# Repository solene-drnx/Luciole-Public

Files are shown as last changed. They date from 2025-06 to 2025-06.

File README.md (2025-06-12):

# 🛋️ Tuto faire une lampe connectée 
Petit dossier pour vous montrer comment faire une lampe connectée.
La lampe a les fonctionnalités suivantes : 
- **Réveil simulateur d'aube** : La lampe monte en luminosité progressive pour te réveiller en douceur en 30 min en fonction de l'heure de ton réveil
- **Radio intégrée** : La lampe intègre une radio pour te permettre d'écouter de la musique ou les informations
- **Contrôle via une application** : La lampe est connectée à une application mobile pour te permettre de contrôler à distance la couleur de cette dernière, la fréquence radio ou encore l'heure des réveils.

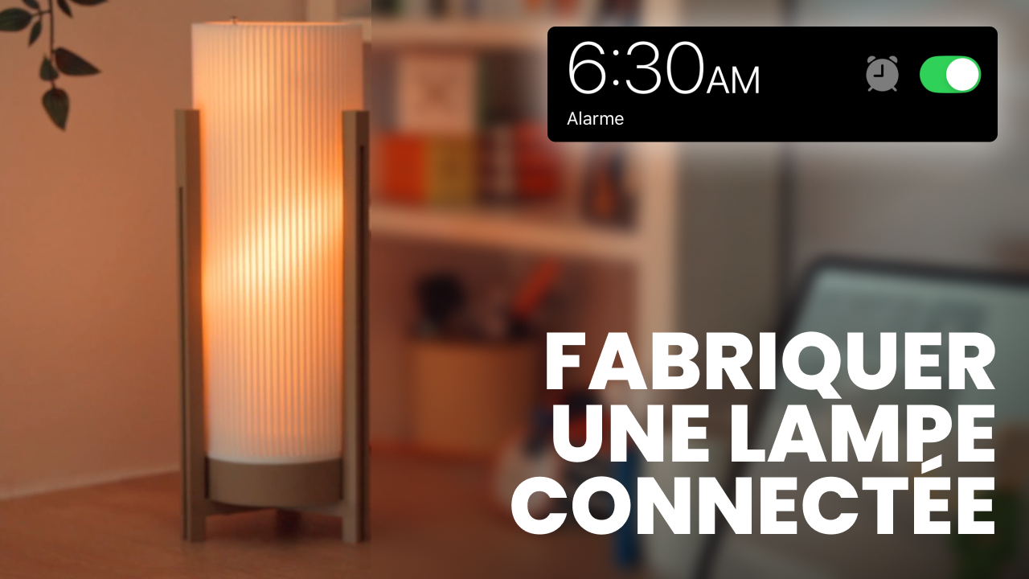
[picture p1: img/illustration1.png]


##  ⚙️ Matériel 
Pour le matériel, il te faudra les composants suivants. Si tu ne veux pas de module radio tu peux prendre uniquement l'ESP32 et le ruban de LED.
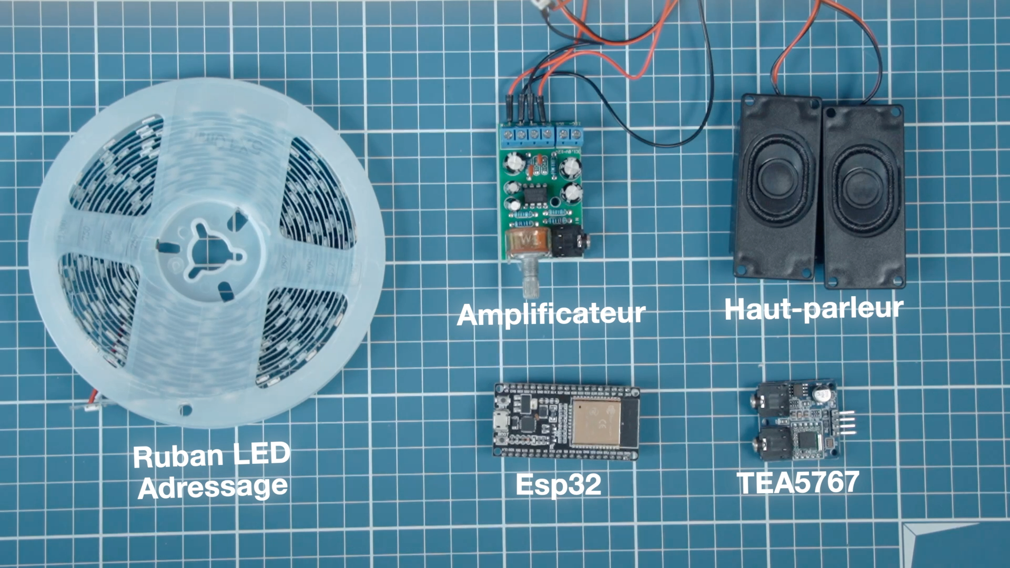
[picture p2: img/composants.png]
composants


| Composant | Prix |
|---|---|
| [ESP32](https://www.amazon.fr/AZDelivery-Development-successeur-Compatible-incluant/dp/B071P98VTG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,aps,90&sr=8-6&th=1) | 10.19 € |
| [Module radio TEA5767](https://www.amazon.fr/ICQUANZX-TEA5767-antenne-t%C3%A9lescopique-76-108MHZ/dp/B07VBVDNLL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) | 9,99 €  | |
| [Amplificateur Audio TDA2822M](https://www.amazon.fr/DC1-8-12V-dAmplificateur-Puissance-Ordinateur-Haut-parleur/dp/B07LG35G22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) | 5 € | |
| [Haut parleur](https://www.amazon.fr/CQRobot-Electronics-JST-PH2-0-Interface-Electronic/dp/B0738NLFTG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) | 7,99 €  | |
| [LED adressables](https://www.amazon.fr/Yeexppz-Dimmable-Individually-Addressable-Intelligent/dp/B0C5R5HMK6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) | 20.29 € | | | |
| [Câble jack jack](https://www.amazon.fr/dp/B07KTYS6FB?ref=ppx_yo2ov_dt_b_fed_asin_title) | 2,35 €  | |

## 🛒 Branchements
Branchements entre le module radio et L'ESP32

| ESP32 | Module Radio TEA5767 | 
| --- |---|
| 5V | 5V | 
| GPIO21 | SDA |
| GPIO22 | SCL | 
| GND | GND |

Ensuite brancher le module Radio TEA5767 avec l'amplificateur Audio TDA2822M grâce au cable jack-jack. Puis brancher l'amplificateur aux deux enceintes et l'alimenter en 5V.  

Branchement entre le ruban de LED et l'ESP32 : 

| ESP32 | Ruban de LED | 
| --- |---|
| 5V | 5V | 
| GPIO2 | DIN |
| GND | GND |

## 🚧 Code ESP32
### Récupérer l'adresse IP locale de l'ESP32
Dans un premier temps, on va récupérer l'adresse IP locale de l'ESP32. Pour cela lance le script [IP local](ESP32/IPlocal/IPlocal.ino) dans le dossier ESP32.  
Ouvrez le `Serial Monitor` pour récupérer l'adresse IP locale de l'ESP32.

### Code final de l'ESP32

Ensuite téléverser le [script final](ESP32/scriptESP32/scriptESP32.ino) dans l'ESP32 qui se situe dans le dossier `script ESP32`.

## 🔮 Application
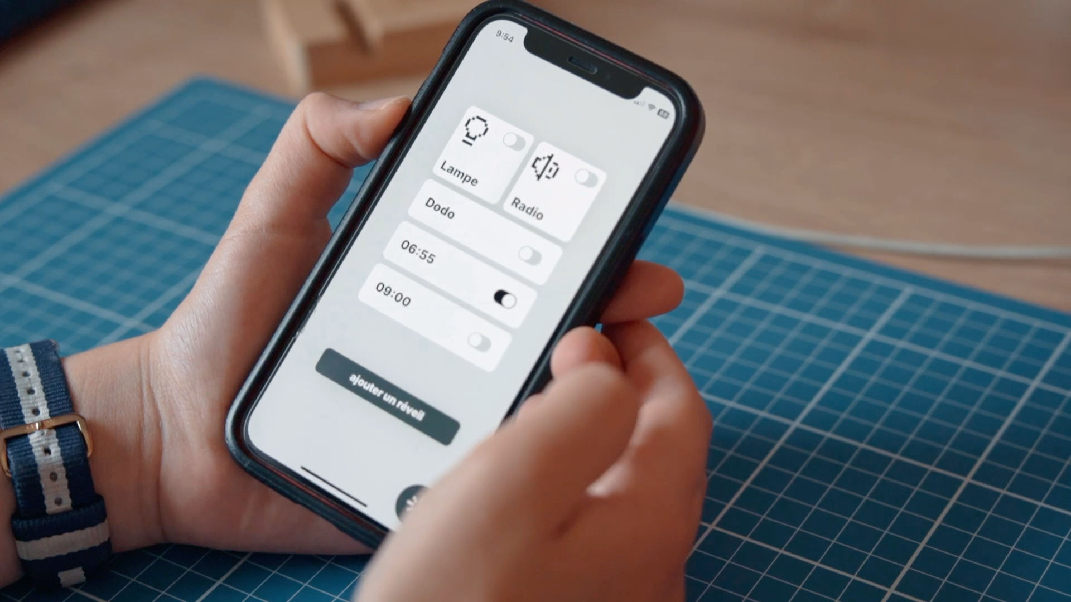
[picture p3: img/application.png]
image application


Il vous faudra les prérequis suivant pour installer l'application. 
- Node.js et npm/yarn.
- Expo CLI installé.

1. Va dans le [dossier ici](Application/):
2. Installe les dépendances : `npm install`
3. Lance l'application : `npx expo start`

Ensuite ajoute l'adresse IP local de l'ESP32 dans le fichier [config.js](Application/config/config.js) pour pouvoir faire en sorte que l'application communique avec l'ESP32.

## Assemblage

Ensuite il vous faudra imprimer les fichiers 3D suivant. Il est important d'imprimer le diffuseur en blanc afin qu'il diffuse la lumière, pour le reste c'est comme vous voulez ✌️

Pour assembler la lampe il faut que tu mette l'ESP32 et les branchement dans le [conteneur électronique](Fichiers%203D/conteneurElectronique.stl). Ensuite tu peux caler la [pièce qui fait le lien avec le cylindre](Fichiers%203D/lienConteneurCylindre.stl). Puis tu peux placer le [cylindre](Fichiers%203D/cylindreLED.stl) au dessus et coller le ruban de LED dessus.

L'assemblage de ces trois pièces devrait ressembler à cela : 
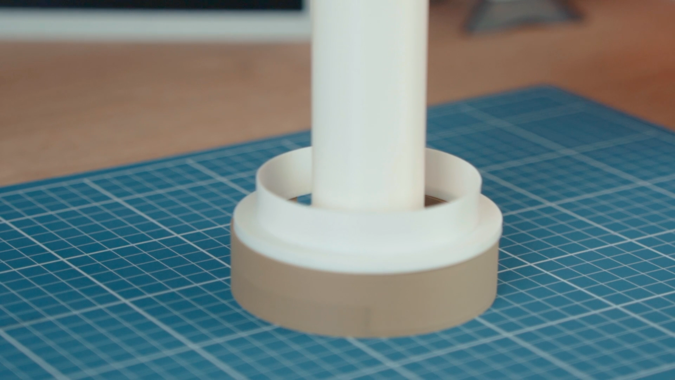
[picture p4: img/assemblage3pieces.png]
assemblage


Tu peux ensuite mettre les enceintes et l'amplificateur dans le cylindre. Tu peux ensuite mettre le [diffuseur](Fichiers%203D/diffuseur.stl) et le [cadre](Fichiers%203D/cadreEnBois.stl).

## Conclusion

Et voila y'a plus qu'à alimenter ta lampe et elle devrait ressembler à ca 🥳

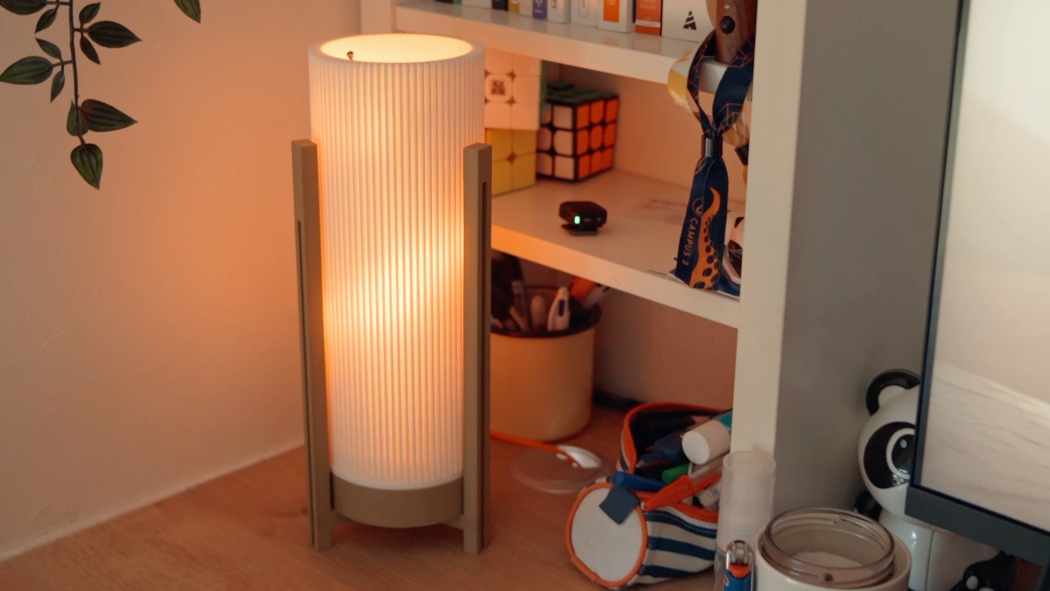
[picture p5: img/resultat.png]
resultat final


Voila voila 🤗  
Des bisous  
Solène

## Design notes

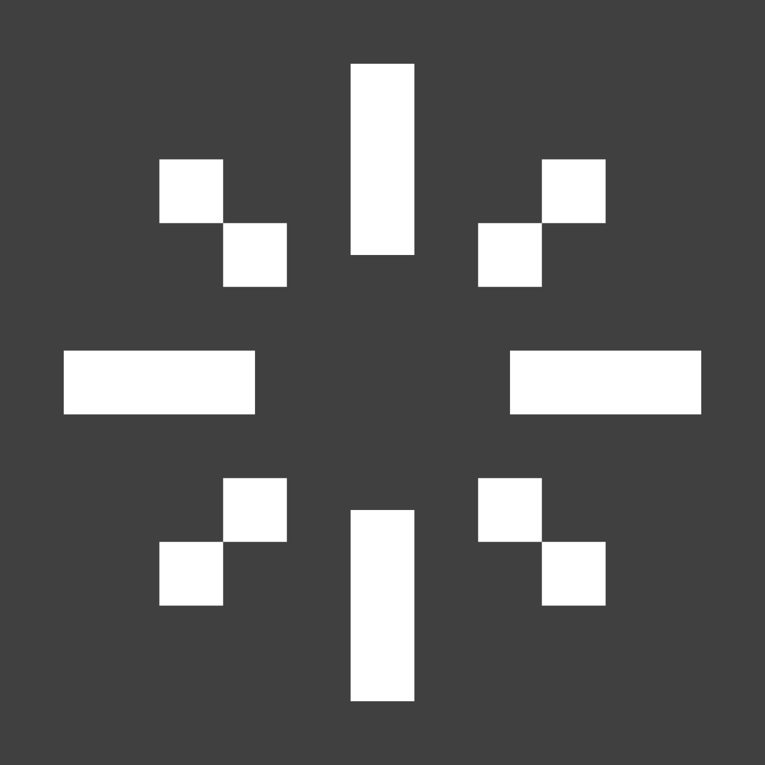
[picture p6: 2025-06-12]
Application/assets/loader.png

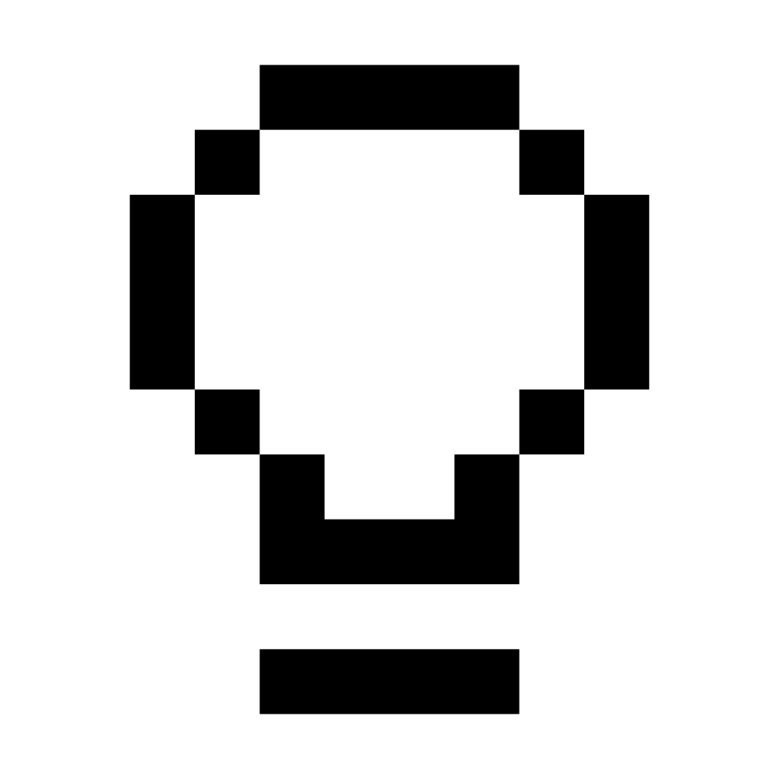
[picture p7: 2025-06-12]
Application/assets/lightbulb.png

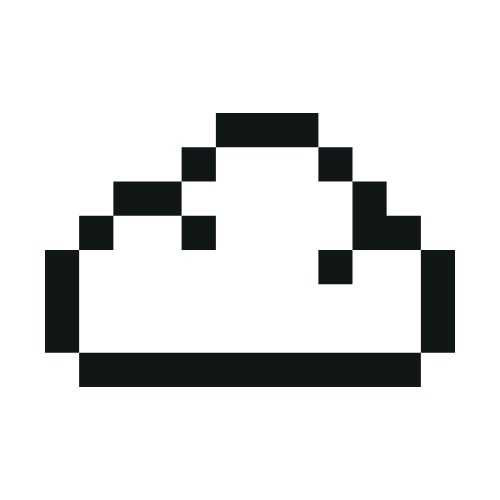
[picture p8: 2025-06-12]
Application/assets/cloud.png

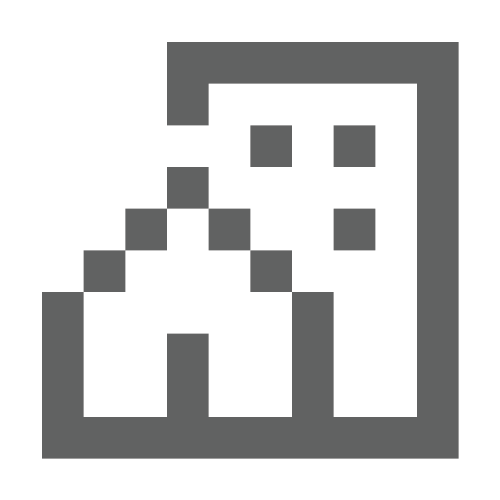
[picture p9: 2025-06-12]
Application/assets/greyBus.png

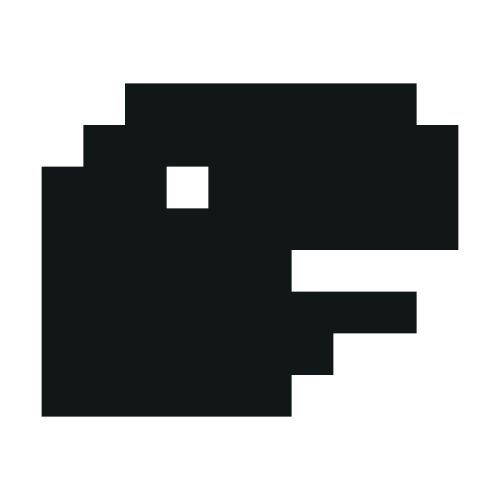
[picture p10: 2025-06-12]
Application/assets/dino.png

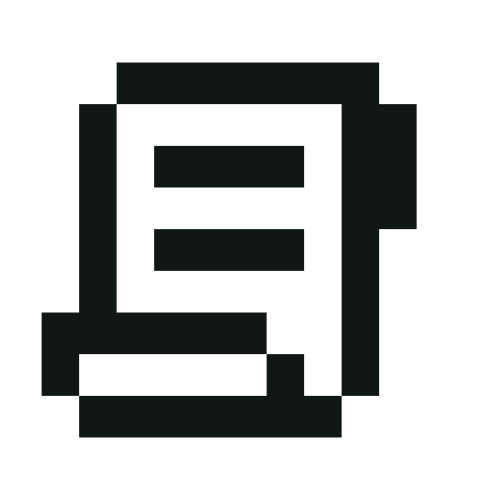
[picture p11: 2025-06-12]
Application/assets/script_text.png

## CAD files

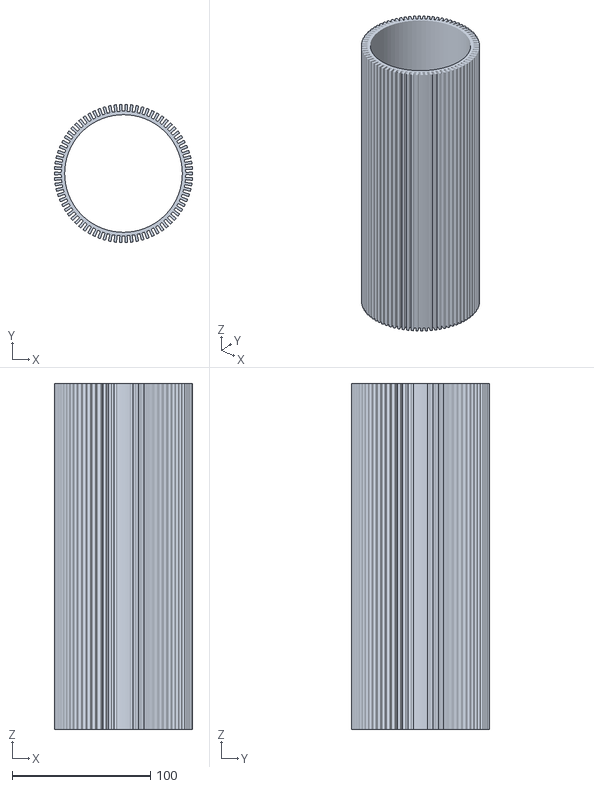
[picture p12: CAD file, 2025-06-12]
Fichiers 3D/diffuseur.stl
100.0 x 100.0 x 250.0

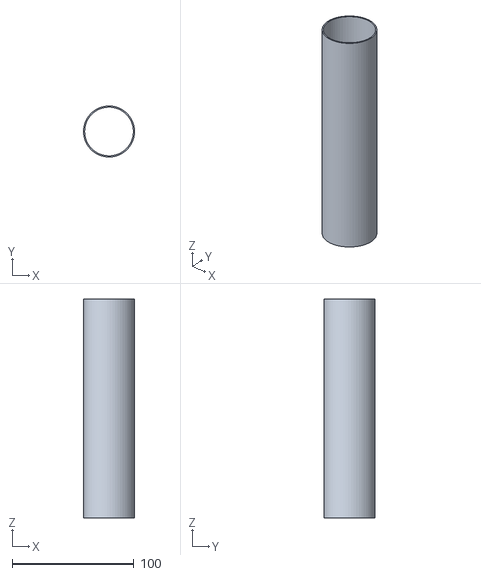
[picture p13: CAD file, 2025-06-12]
Fichiers 3D/cylindreLED.stl
42.0 x 42.0 x 180.0

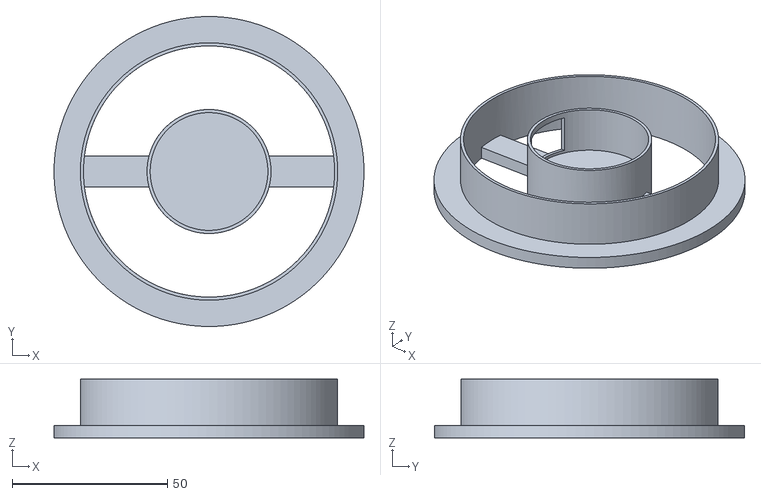
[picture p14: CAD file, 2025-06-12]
Fichiers 3D/lienConteneurCylindre.stl
100.0 x 100.0 x 19.0

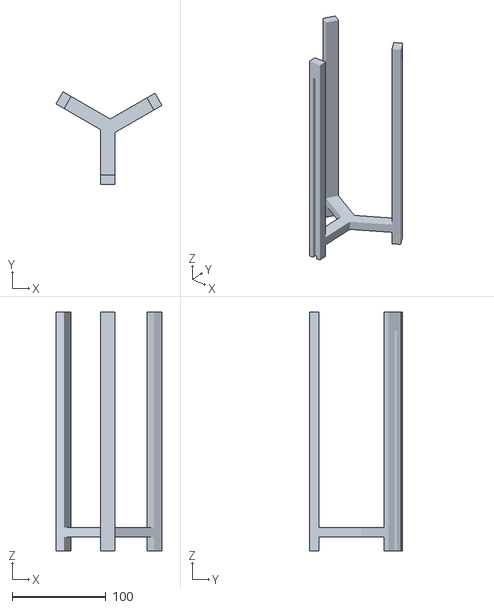
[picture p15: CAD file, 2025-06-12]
Fichiers 3D/cadreEnBois.stl
113.2 x 98.8 x 255.0

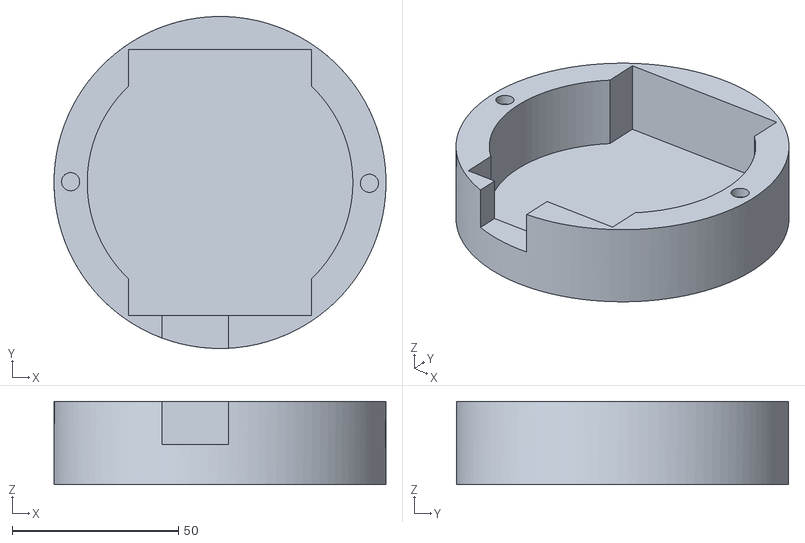
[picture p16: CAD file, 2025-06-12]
Fichiers 3D/conteneurElectronique.stl
100.0 x 100.0 x 25.0

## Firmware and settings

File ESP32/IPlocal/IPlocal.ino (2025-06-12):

#include <WiFi.h>

// Setup wifi (remplacer par ton wifi)
const char* ssid = "le nom de ton wifi";
const char* password = "ton piti mot de passe";

void setup() {
  Serial.begin(115200);
  WiFi.begin(ssid, password);
  Serial.print("Connexion au WiFi");
  while (WiFi.status() != WL_CONNECTED) {
    delay(500);
    Serial.print(".");
  }

  Serial.println("");
  Serial.println("Connecté au WiFi !");
  Serial.print("Adresse IP locale : ");
  Serial.println(WiFi.localIP()); 
}

void loop() {
  // Blablablablabla
}

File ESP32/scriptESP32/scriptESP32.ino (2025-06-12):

#include <WiFi.h>
#include <Wire.h>
#include <TEA5767Radio.h>
#include <FastLED.h>
#include <TEA5767.h>
#include "time.h"

// Setup wifi (remplacer par vos identifiants)
const char* ssid = "le petit nom de ton wifi";
const char* password = "ton pitit mot de passe";
WiFiServer server(80);

// Setup LEDs
#define NUM_LEDS 20
#define DATA_PIN 2
#define LED_TYPE WS2812B
#define COLOR_ORDER GRB
CRGB leds[NUM_LEDS];
#define BRIGHTNESS 255

// Setup module radio
TEA5767 radio;
int heureReveil;
int minuteReveil;

// Setup pour récuperer l'heure
const char* ntpServer = "pool.ntp.org";
const long gmtOffset_sec = 3600;
const int daylightOffset_sec = 3600;
struct tm timeinfo;

void printLocalTime() {
  if (!getLocalTime(&timeinfo)) {
    Serial.println("Failed to obtain time");
    return;
  }
}

// Fonction Réveil simulateur d'aube
void ledReveil() {
  Serial.println("REVEILLL");
  int luminosite = 0;
  while (luminosite <= 100) {
    luminosite = luminosite + 1;
    FastLED.setBrightness(luminosite);
    for (int i = 0; i < NUM_LEDS; i++) {
      leds[i] = CRGB(255, 100, 0);
    }
    FastLED.show();
    delay(18000);
  }
  for (int i = 0; i < NUM_LEDS; i++) {
    leds[i] = CRGB(255, 100, 0);
  }
  FastLED.show();
  radio.setMute(false);
}

void setup() {
  // Communication
  Serial.begin(115200);
  Wire.begin();
  FastLED.addLeds<LED_TYPE, DATA_PIN, COLOR_ORDER>(leds, NUM_LEDS).setCorrection(TypicalLEDStrip);
  FastLED.setBrightness(BRIGHTNESS);
  for (int i = 0; i < NUM_LEDS; i++) {
    leds[i] = CRGB(0, 0, 0);
  }
  FastLED.show();
  WiFi.begin(ssid, password);
  Serial.print("Connexion au WiFi");
  while (WiFi.status() != WL_CONNECTED) {
    delay(500);
    Serial.print(".");
  }

  Serial.println("\nConnecté au WiFi.");
  Serial.print("Adresse IP: ");
  Serial.println(WiFi.localIP());

  server.begin();
  radio.init();
  radio.debugEnable();
  // radio.setBandFrequency(RADIO_BAND_FM, 10550); // France info
  radio.setBandFrequency(RADIO_BAND_FM, 9530); // France inter
  configTime(gmtOffset_sec, daylightOffset_sec, ntpServer);
  printLocalTime();
}

void loop() {
   // Check wifi
  WiFiClient client = server.available();
  if (client) {
    Serial.println("Client connecté.");

    String currentLine = "";
    String message = "";
    String valeurMessage = "";
    while (client.connected()) {
      if (client.available()) {
        char c = client.read();
        Serial.write(c);

        if (c == '\n') {
          if (currentLine.length() == 0) {
            client.println("HTTP/1.1 200 OK");
            client.println("Content-Type: application/json");
            client.println("Connection: close");
            client.println();
            client.println("{\"status\": \"Message reçu\"}");

            Serial.print("Message reçu: ");
            Serial.println(message);
            Serial.print("Valeur message: ");
            Serial.println(valeurMessage);
            break;
          } else {
            if (currentLine.startsWith("GET /?message=")) {
              message = currentLine.substring(14, 19);
              // ALLUMER ET ETTEINDRE LA LAMPE OU RADIO
              if (message == "lampe") {
                valeurMessage = currentLine.substring(19, 21);
                if (valeurMessage == "on") {
                  for (int i = 0; i < NUM_LEDS; i++) {
                    leds[i] = CRGB(250, 100, 0);
                  }
                } else {
                  for (int i = 0; i < NUM_LEDS; i++) {
                    leds[i] = CRGB(0, 0, 0);
                  }
                }
                FastLED.show();
              } else if (message == "radio") {
                valeurMessage = currentLine.substring(19, 21);
                if (valeurMessage == "on") {
                  radio.setMute(false);
                } else {
                  radio.setMute(true);
                }
              } else if (message == "color") {
                // CHANGER COULEUR LED
                valeurMessage = currentLine.substring(22, 28);
                int r, g, b;
                sscanf(valeurMessage.c_str(), "%02x%02x%02x", &r, &g, &b);
                Serial.println(r);
                Serial.println(g);
                Serial.println(b);
                for (int i = 0; i < NUM_LEDS; i++) {
                  leds[i] = CRGB(r, g, b);
                }
                FastLED.show();
              } else if (message == "alarm") {
                valeurMessage = currentLine.substring(19);
                valeurMessage = valeurMessage.substring(0, valeurMessage.indexOf(" "));
                if (valeurMessage.indexOf("%") != -1) {
                  heureReveil = valeurMessage.substring(0, valeurMessage.indexOf("%")).toInt();
                  minuteReveil = valeurMessage.substring(valeurMessage.indexOf("%") + 3).toInt();
                  Serial.print("heure : ");
                  Serial.print(heureReveil);
                  Serial.print(" | minute : ");
                  Serial.print(minuteReveil);
                }
              } else {
                // CHANGER FREQUENCE RADIO
                valeurMessage = currentLine.substring(19);
                valeurMessage = valeurMessage.substring(0, valeurMessage.indexOf(" "));
                if (valeurMessage.indexOf("%") != -1) {
                  valeurMessage = valeurMessage.substring(0, valeurMessage.indexOf("%")) + "." + valeurMessage.substring(valeurMessage.indexOf("%") + 3);
                }
                Serial.println(valeurMessage.toDouble() * 100);
                radio.setBandFrequency(RADIO_BAND_FM, (valeurMessage.toDouble() * 100));
              }
            }
            currentLine = "";
          }
        } else if (c != '\r') {
          currentLine += c;
        }
      }
    }
    client.stop();
    Serial.println("Client déconnecté.");
  }
  // Met à jour timeinfo
  printLocalTime();

  // Vérification de l'heure pour le réveil
  int adjustedHour = heureReveil;
  int adjustedMin = minuteReveil - 30;

  if (adjustedMin < 0) {
    adjustedMin += 60;
    adjustedHour--;
    if (adjustedHour < 0) {
      adjustedHour = 23;
    }
  }

  if (timeinfo.tm_hour == adjustedHour && timeinfo.tm_min == adjustedMin) {
      Serial.print("Réveil prévu à : ");
      Serial.print(adjustedHour);
      Serial.print(":");
      if (adjustedMin < 10) {
        Serial.print("0");
      }
      Serial.println(adjustedMin);
      ledReveil();
    }
    delay(200);
}

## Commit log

2025-06-12 partie esp32 🤖
2025-06-12 partie esp32
2025-06-12 maj final du readme j'espr
    [cadreEnBois.stl, conteneurElectronique.stl, cylindreLED.stl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]
